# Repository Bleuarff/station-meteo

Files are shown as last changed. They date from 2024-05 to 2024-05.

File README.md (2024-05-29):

# Station Meteo

A multi-points, LoRa-based weather monitoring system.

Comprises:
- base station: display + Temp, humidity and CO2 sensors
- outdoor satellite: Temp, humidity and pressure sensors
- indoor satellite: Temp, humidity and CO2 sensors

# Notes

- Satellites to capture sensor values every 5 min and send to base over LoRa 433MHz
- Base updates screen every 5min
- battery-operated
- base, outdoor and indoor sats all have different firmwares.
- Display: 1 line per satellite, with freshness indicator (whether measure was received over last X min)

# TODO
- circuit diagrams
- breakout builds
- code
- assembly
- shells
- PCB

# BOM

Type | Name | Refs
-|-|-
Microcontroller | Heltec CubeCell HTCC-AB02A | https://heltec.org/project/htcc-ab02a/?attribute_pa_band=433mhz
Temp & humidity sensor | AHT20 | https://www.adafruit.com/product/4566
CO2 sensor | SCD40 | https://www.adafruit.com/product/5187
Pressure sensor | LPS22HB | https://www.adafruit.com/product/4633
screen | eInk 2.13" monochrome 250x122 (SSD1680) | https://www.adafruit.com/product/4197

# Parts documentation

Name | Url
-|-
AHT20 | https://asairsensors.com/wp-content/uploads/2021/09/Data-Sheet-AHT20-Humidity-and-Temperature-Sensor-ASAIR-V1.0.03.pdf
LPS22HB | https://www.mouser.fr/pdfdocs/enDM00140895.pdf
SCD40 | https://sensirion.com/media/documents/48C4B7FB/64C134E7/Sensirion_SCD4x_Datasheet.pdf
Screen | https://learn.adafruit.com/adafruit-2-13-eink-display-breakouts-and-featherwings
CubeCell | https://resource.heltec.cn/download/CubeCell/HTCC-AB02A/HTCC-AB02A_PinoutDiagram.pdf <br> https://docs.heltec.org/en/node/asr650x/htcc_ab02/index.html <br>

# Setup

- Create a symlink for each library:
````bash
ln -s ~/dev/station-meteo/sketches/libraries/aht20 ~/dev/station-meteo/sketches/libraries/lps22hb ~/Arduino/libraries/
````

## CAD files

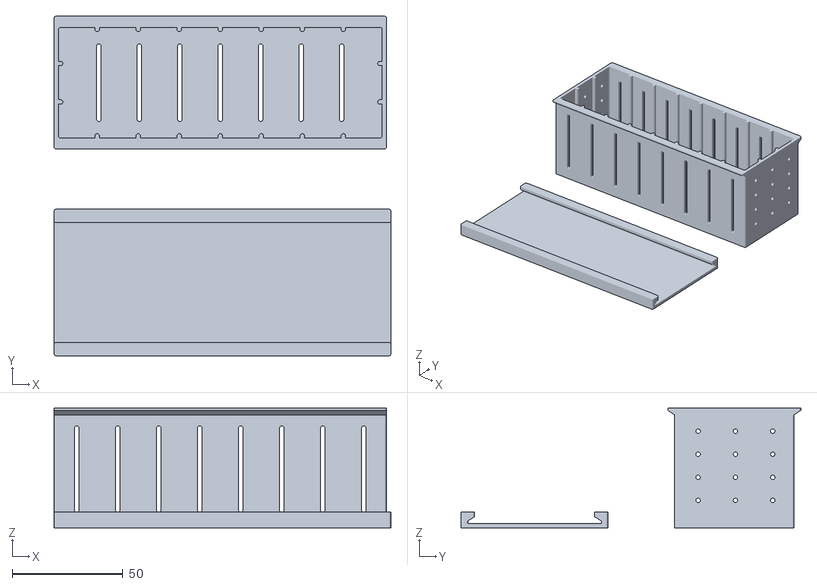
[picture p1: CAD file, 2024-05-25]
cases/testcase.stl
152.0 x 153.2 x 54.0

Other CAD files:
cases/testcase1.FCStd

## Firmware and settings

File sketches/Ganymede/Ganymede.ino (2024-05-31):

/***************************************
 *
 * Ganymede: the outdoor module
 *      - temperature
 *      - humidity
 *      - atmospheric pressure
 *
 ***************************************/

#include <Wire.h>
#include <aht20.h>
#include <lps22hb.h>

// interval between loop checks
// actual production value: 5min (5 * 60 * 1000)
const unsigned long SLEEP_INTERVAL = 10000;

uint8_t lowpowermode = 0;

static TimerEvent_t wakeup;

AHT20 aht20;
LPS22HB lps22;

float temp, humid, pressure, temp2;

void setup() {
  Serial.begin(115200);
  pinMode(Vext, OUTPUT);
  digitalWrite(Vext, LOW);  // power i2c sensors
  Wire.begin();

  delay(2000);
  Serial.println("** Ganymede starting **");

  TimerInit(&wakeup, onWakeup);
}

// Prepare for sleep: close i2c bus, pull Vext OFF
void onSleep() {
  Wire.end();
  delay(100);
  digitalWrite(Vext, HIGH);
  TimerSetValue(&wakeup, SLEEP_INTERVAL);
  TimerStart(&wakeup);
  lowpowermode = 1;
}

// wake up: pull Vext ON and start i2c bus
void onWakeup() {
  digitalWrite(Vext, LOW);
  Wire.begin();
  lowpowermode = 0;
  delay(500);
}

void loop() {
  if (lowpowermode){
    // put cpu in deep sleep
    lowPowerHandler();
  }
  else {
    // take a measure before going back to sleep
    takeMeasure();
    delay(100);
    onSleep();
  }
}

void takeMeasure() {
  aht20.begin();
  lps22.begin();

  if (aht20.isReady) {
    // Retrieve value from temp & humidity sensors
    aht20.getValues(&temp, &humid);
  }

  lps22.getValues(&pressure, &temp2);
  Serial.printf("T: %2.1f°\tH: %2.1f%%\tP: %4.1fhPa\tT2: %2.1f°\n", temp, humid, pressure, temp2);
}

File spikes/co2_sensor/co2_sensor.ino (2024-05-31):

/*
  Test how to work with SCD40 CO2 sensor.
  Use driver from https://github.com/Sensirion/arduino-i2c-scd4x/tree/master
*/

#include <Wire.h>
#include <SensirionI2CScd4x.h>

SensirionI2CScd4x scd4x;

void setup() {
  Serial.begin(115200);
  Wire.begin();

  delay(6000);
  Serial.println("--SCD40 Tests--");
  scd4x.begin(Wire);
  scd4x.stopPeriodicMeasurement();

  scd4x.startPeriodicMeasurement();

  Serial.println("Waiting for first measurement... (5 sec)");
}


void loop() {
  delay(6000);
  
  bool ready = false;
  scd4x.getDataReadyFlag(ready);

  if (ready){
    uint16_t co2;
    float temperature, humidity;

    scd4x.readMeasurement(co2, temperature, humidity);
    Serial.print("Co2:");
          Serial.print(co2);
          Serial.print("\t");
          Serial.print("Temperature:");
          Serial.print(temperature);
          Serial.print("\t");
          Serial.print("Humidity:");
          Serial.println(humidity);
  }
  else {
    Serial.println("Data not ready");
  }
}

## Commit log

2024-05-04 Add kicad schematics
    schematics for base station and satellites.
    [satellite-indoor.kicad_sch, satellite-outdoor.kicad_sch, station-meteo.kicad_sch]
2024-05-22 Add test freecad model
    test case model to play with freecad.
    [testcase1.FCStd]
2024-05-24 AHT20 init & reading
    Use wire.h to communicate with AHT20.
2024-05-25 Compute temperature
    [testcase.stl, tuto1.FCStd]
2024-05-25 Move AHT20 code to library
    sensor init & readings moved to its own lib.
2024-05-25 Remove tuto case file
    [tuto1.FCStd]
2024-05-25 Set lps22 i2c address
    connect SDO to GND to set address 0x5C;
    [satellite-outdoor.kicad_sch]
2024-05-25 Revert "Set lps22 i2c address"
    This reverts commit cf4319b74ca7d706c925089c18308ba03ea26221.
    [satellite-outdoor.kicad_sch]
2024-05-25 Fix LPS22 connection pinout
    I2C SDA is SDI pin, not SD0.
    [satellite-outdoor.kicad_sch]
2024-05-26 Spike for pressure sensor LPS22HB
2024-05-27 LPS22: doc & status reading
    - doc
    - check both temp and pressure status before reading.
2024-05-27 Enable multi-byte read
    set bit IF_ADD_INC in CTRL_REG2 to allow reading all pressure and temp bytes at once.
2024-05-27 cleanup pressure spike
2024-05-27 AHT20 refactor
    -init renamed begin and returns void
    -sensor readiness variable stored by class instance
2024-05-27 Ganymede: get pressure value
2024-05-29 Test spike for co2 sensor
2024-05-29 Schematics update: use Vext instead of VDD
    Vext can be controllled and switched on/off.
    [satellite-indoor.kicad_sch, satellite-outdoor.kicad_sch, station-meteo.kicad_sch]
2024-05-29 gitignore update for kicad temp file
2024-05-31 Schematics/ add i2c pullups on outdoor sat.
    20ko should do the trick.
    [satellite-outdoor.kicad_sch, station-meteo.kicad_sch]
2024-05-31 Use deep sleep in main sketch
    Change to using sleep/wakeup functions.
    Turn i2c devices off during sleep
